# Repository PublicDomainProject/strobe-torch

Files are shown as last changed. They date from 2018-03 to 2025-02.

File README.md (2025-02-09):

# Strobe Torch
## Purpose
Little flashlight (or torch in UK) to calibrate the speed of a turntable with the help of a strobe disc or the strobe rings along the platter.

To use such strobe discs one needs a light source with a 50, 60 or 300 Hz strobe light. In the older days a simple light bulb with filament was enough to did the job. In the time of LEDs and compact fluorescent light sources one needs an additional helper like this to work with a strobe disc.

The needed frequency depends on your strobe disc. Most of them have at least 50 and 60 Hz in parallel (or two sides). There are "high-resolution" strobe discs that need a 300 Hz light source for calibration.

Also because this strobe torch uses a crystal oscillator it is more precise than a light bulb.

## Usage
The device is designed to be very simple to use.

There are three momentary buttons on the front. Each button represents one frequency. So simply press the 50 Hz button and you get a white light beam that flickers with 50 Hz.

When you release the button, the light goes off and the device consumes no energy.

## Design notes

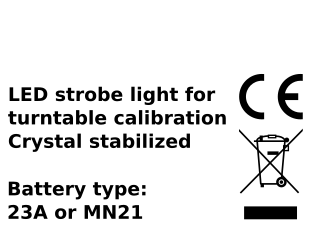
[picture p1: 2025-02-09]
case/Teko 11123 sticker white.png

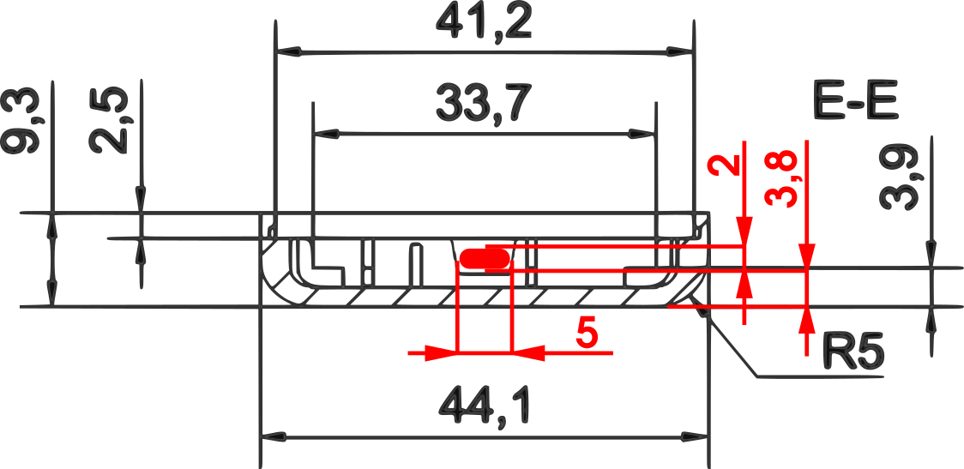
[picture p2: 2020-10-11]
case/Teko 11123 milling.png

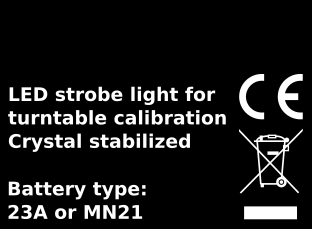
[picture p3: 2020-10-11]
case/Teko 11123 sticker.png

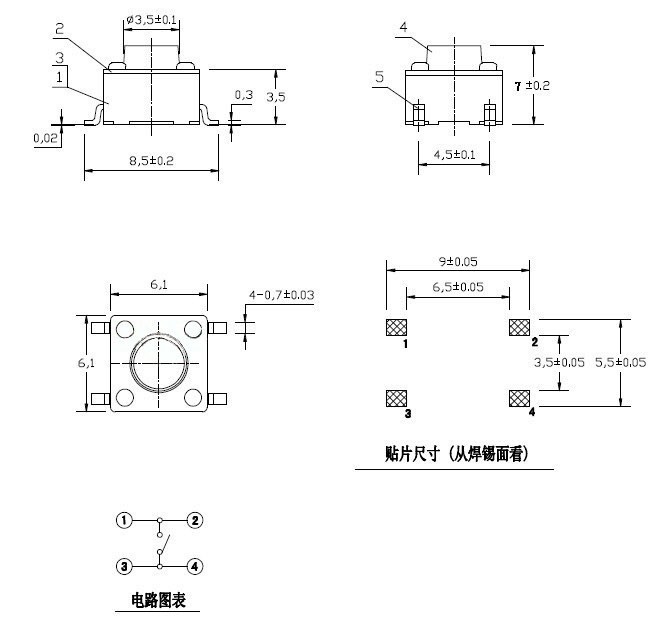
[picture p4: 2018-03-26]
datasheets/HTB1ZU.EGVXXXXXcXXXXq6xXFXXXH.jpg

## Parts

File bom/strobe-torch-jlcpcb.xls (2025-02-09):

Comment | Designator | Footprint | JLCPCB Part #
100n Unpolarized capacitor | C1 | 805
20pF Unpolarized capacitor | C2, C3 | 603
LED White Sideemitting 2.8*1,2*0,8mm | D1, D2 | 215
LED Green InGaN | D3 | 603 | C2288
BAT54A schottky barrier diode | D4, D5 | SOT-23 | C83936
BSS138 50V Vds, 0.22 A Id, N-channel MOSFET | Q1 | SOT-23 | C52895
1k8 Resistor | R1 | 603
150 Resistor | R2 | 603
Push button switch, SPST | SW1, SW3 | FSM6JSMA | C178262
ATTINY25V-10SU 2kB Flash, 128B EEPROM | U1 | SO-8 Wide 5.3x6.2mm
Crystal 4.9152MHz, two pin, SMD | Y1 | HC49-SD | C21921

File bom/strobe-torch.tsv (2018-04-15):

References | Qty | Description | Package | Manufacturer | Partnummer
BT1 | 1 | Battery compartment of the case |  | Teko | 1112x
C1 | 1 | 100n Unpolarized capacitor | 0805
C2, C3 | 2 | 20pF Unpolarized capacitor | 0603
D1, D2 | 2 | LED White Sideemitting 2.8*1,2*0,8mm | 215 | Xiasongxin | 215 White SMD LED 2.8*1,2*0,8mm
D3 | 1 | LED Green InGaN | 0603 | Everlight | 19-213/GHC-XS1T1N/3T
D4, D5 | 2 | BAT54A schottky barrier diode | SOT-23
Q1 | 1 | BSS138 50V Vds, 0.22 A Id, N-channel MOSFET | SOT-23
R1 | 1 | 1k8 Resistor | 0603
R2 | 1 | 150 Resistor | 0603
SW1, SW2, SW3 | 3 | Push button switch, SPST | PTS645
U1 | 1 | ATTINY25V-10SU 2kB Flash, 128B EEPROM | SO-8 Wide 5.3x6.2mm | Microchip
Y1 | 1 | Crystal 4.9152MHz, two pin, SMD | HC49-SD

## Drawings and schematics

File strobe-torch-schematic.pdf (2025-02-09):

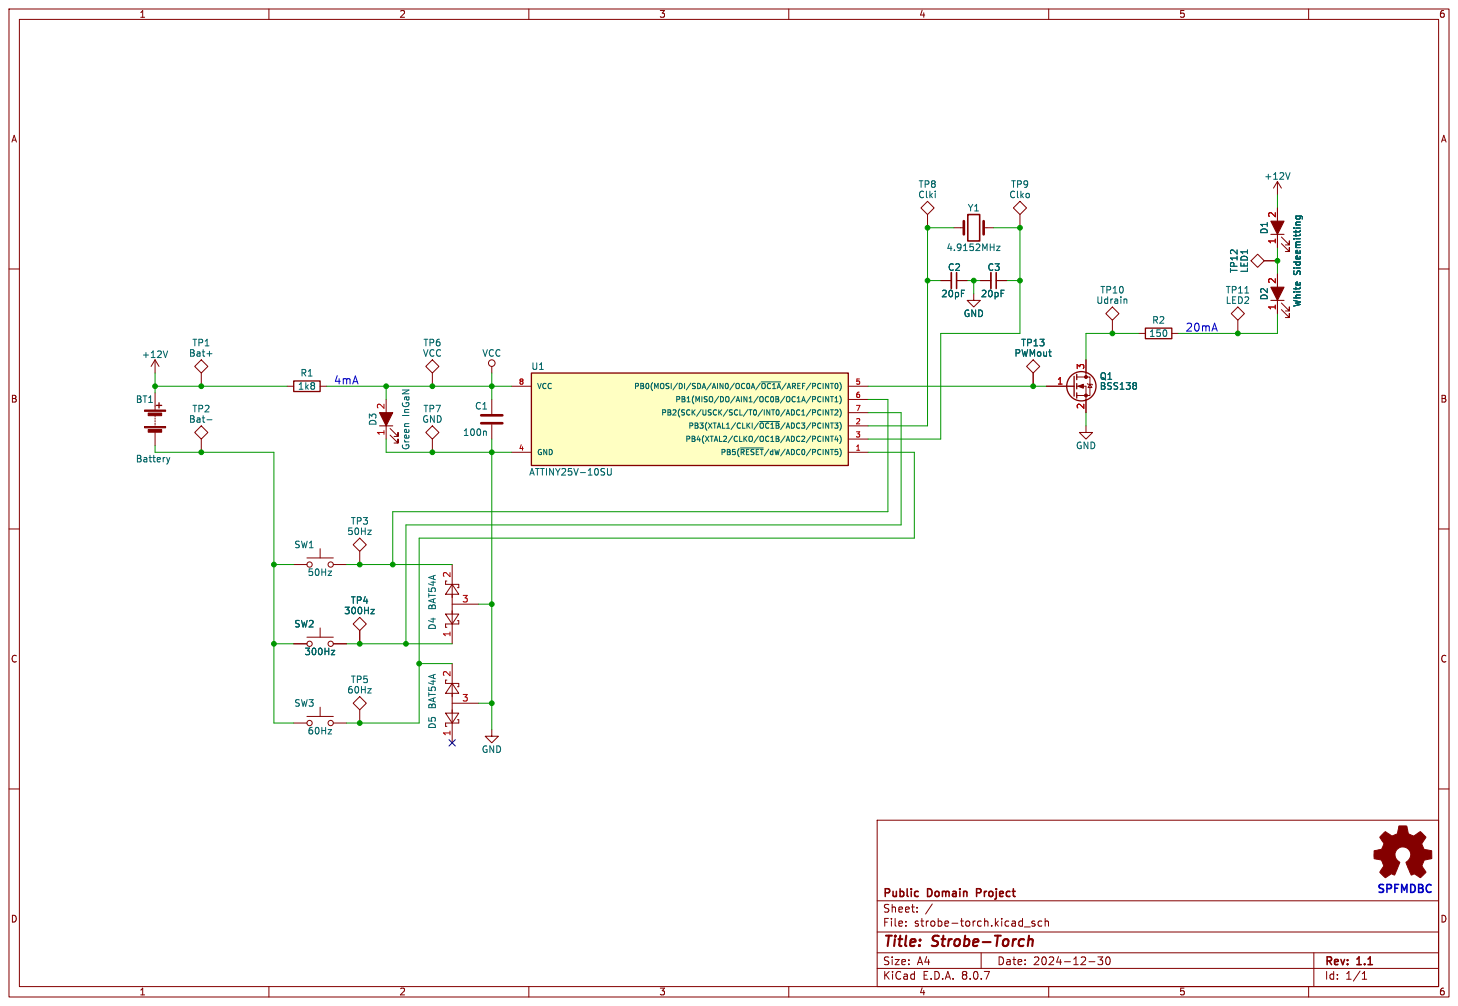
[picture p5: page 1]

1 2 D3 Green InGaN TP7 GND GND

Id: 1/1 Title: Strobe-Torch

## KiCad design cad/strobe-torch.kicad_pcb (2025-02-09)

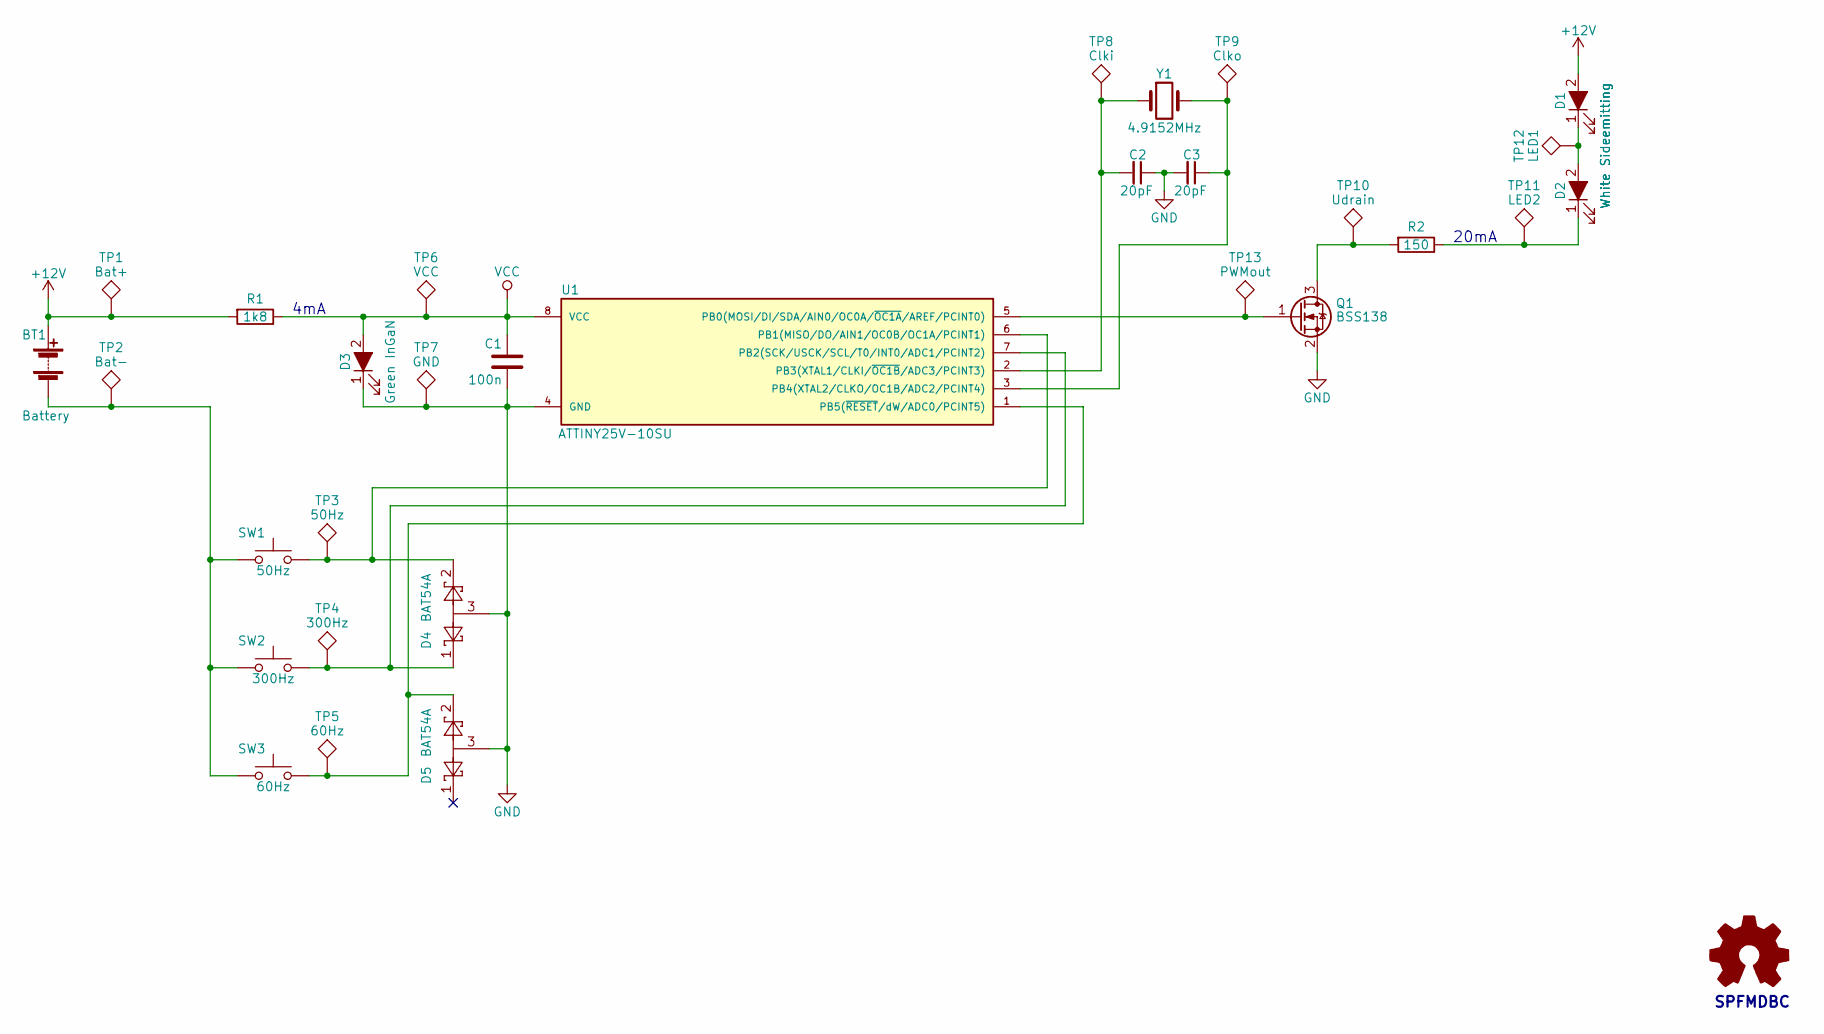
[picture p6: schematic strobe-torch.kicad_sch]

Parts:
BT1: Battery; Teko_1112x_battery_compartment
C1: 100n; C_0805
C2, C3: 20pF; C_0603
D1, D2: White Sideemitting; LED_215; Partnummer 215 White SMD LED 2.8*1,2*0,8mm
D3: Green InGaN; LED_0603; Partnummer 19-213/GHC-XS1T1N/3T
D4, D5: BAT54A; SOT-23
Q1: BSS138; SOT-23
R1: 1k8; R_0603
R2: 150; R_0603
SW1: 50Hz; SW_SPST_FSM6JSMA
SW2: 300Hz; SW_SPST_FSM6JSMA
SW3: 60Hz; SW_SPST_FSM6JSMA
TP1: Bat+; Measurement_Point_Round-SMD-Pad_Small
TP2: Bat-; Measurement_Point_Round-SMD-Pad_Small
TP3: 50Hz; Measurement_Point_Round-SMD-Pad_Small
TP4: 300Hz; Measurement_Point_Round-SMD-Pad_Small
TP5: 60Hz; Measurement_Point_Round-SMD-Pad_Small
TP6: VCC; Measurement_Point_Round-SMD-Pad_Small
TP7: GND; Measurement_Point_Round-SMD-Pad_Small
TP8: Clki; Measurement_Point_Round-SMD-Pad_Small
TP9: Clko; Measurement_Point_Round-SMD-Pad_Small
TP10: Udrain; Measurement_Point_Round-SMD-Pad_Small
TP11: LED2; Measurement_Point_Round-SMD-Pad_Small
TP12: LED1; Measurement_Point_Round-SMD-Pad_Small
TP13: PWMout; Measurement_Point_Round-SMD-Pad_Small
U1: ATTINY25V-10SU; SO-8_5.3x6.2mm_Pitch1.27mm
Y1: 4.9152MHz; Crystal_SMD_HC49-SD

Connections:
+12V: BT1.1 (+), D1.2 (A), R1.2, TP1.1
GND: C1.2, C2.1, C3.2, D3.1 (K), D4.3, D5.3, Q1.2 (S), TP7.1, U1.4 (GND)
unnamed: BT1.2 (-), SW1.1, SW2.1, SW3.1, TP2.1
unnamed: D1.1 (K), D2.2 (A), TP12.1
unnamed: D2.1 (K), R2.1, TP11.1
unnamed: Q1.3 (D), R2.2, TP10.1
unnamed: Q1.1 (G), TP13.1, U1.5 (PB0(MOSI/DI/SDA/AIN0/OC0A/~OC1A/AREF/PC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)
unnamed: D4.2, SW1.2, TP3.1, U1.6 (PB1(MISO/DO/AIN1/OC0B/OC1A/PCINT1))
unnamed: D4.1, SW2.2, TP4.1, U1.7 (PB2(SCK/USCK/SCL/T0/INT0/ADC1/PCINT2))
unnamed: C2.2, TP8.1, U1.2 (PB3(XTAL1/CLKI/~OC1B/ADC3/PCINT3)), Y1.1
unnamed: C3.1, TP9.1, U1.3 (PB4(XTAL2/CLKO/OC1B/ADC2/PCINT4)), Y1.2
unnamed: D5.2, SW3.2, TP5.1, U1.1 (PB5(~RESET/dW/ADC0/PCINT5))
VCC: C1.1, D3.2 (A), R1.1, TP6.1, U1.8 (VCC)

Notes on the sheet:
4mA
20mA
SPFMDBC

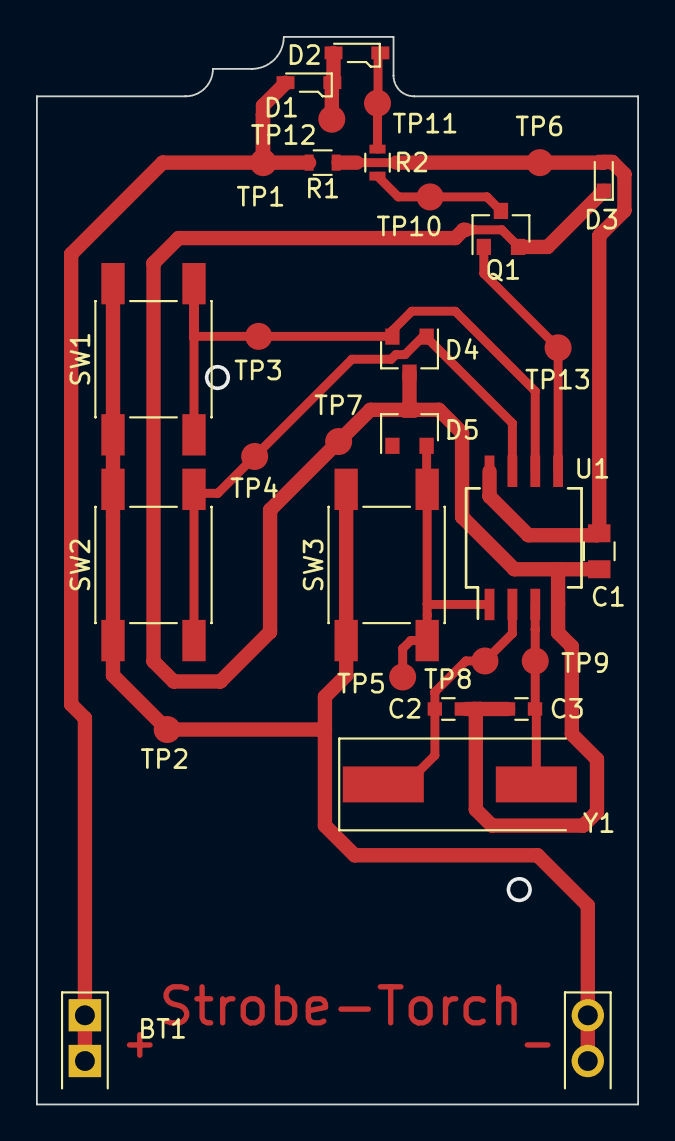
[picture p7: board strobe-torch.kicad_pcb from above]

Board: 2 copper layers, 33.4 x 59.3 mm, 30 parts (0 on the bottom side), 13 nets.

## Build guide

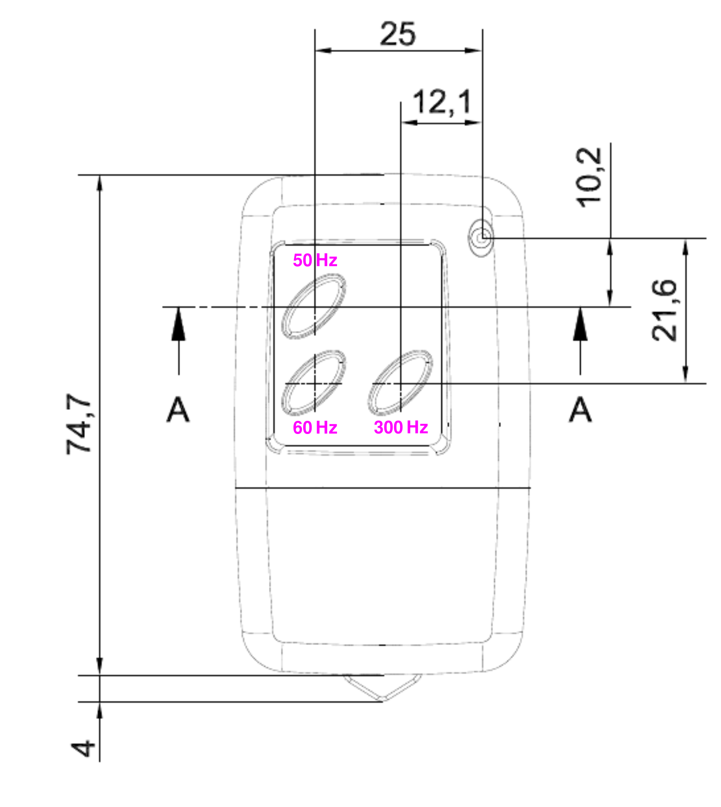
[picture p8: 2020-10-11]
case/Teko 11123 printing.png

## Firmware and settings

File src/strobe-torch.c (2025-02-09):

/***************************************************************************
 * Strobe-Torch
 * (c) 2018 Christoph Zimmermann
 *
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
 * Written by Christoph Zimmermann <nuess0r@pdproject.org>, 2018.
 *
 ***************************************************************************
 * Fuse bit configuration:
 *   - Production setting with 60 Hz mode and disabled reset input
 *   Ext. Crystal Osc.; Frequency 3.0-8.0 MHz; Start-up time PWRDWN/RESET: 258 CK/14 CK + 4.1 ms; [CKSEL=1100 SUT=00]
 *   Clock output on PORTB4 disabled; [CKOUT=0]
 *   Divide clock by 8 internally enabled; [CKDIV8=0]
 *   Brown-out detection disabled; [BODLEVEL=111]
 *   Debug Wire disabled; [DWEN=1] * (only during development)
 *   Preserve EEPROM memory through the Chip Erase cycle disabled; [EESAVE=0]
 *   Reset Disabled (Enable PB5 as i/o pin); [RSTDISBL=0] *
 *   Serial program downloading (SPI) enabled; [SPIEN=0] *
 *   Watch-dog Timer disabled; [WDTON=0]
 *   Self Programming disabled; [SELFPRGEN=0]
 *   AVRDUDE_FUSEBITS = -U hfuse:w:0x5F:m -U lfuse:w:0x4C:m -U efuse:w:0xFF:m

 *   - Development setting without 60 Hz mode (two button only) and enabled reset input (reprogramming possible)
 *   Ext. Crystal Osc.; Frequency 3.0-8.0 MHz; Start-up time PWRDWN/RESET: 258 CK/14 CK + 4.1 ms; [CKSEL=1100 SUT=00]
 *   Clock output on PORTB4 disabled; [CKOUT=0]
 *   Divide clock by 8 internally enabled; [CKDIV8=0]
 *   Brown-out detection disabled; [BODLEVEL=111]
 *   Debug Wire disabled; [DWEN=1] * (only during development)
 *   Preserve EEPROM memory through the Chip Erase cycle disabled; [EESAVE=0]
 *   Reset Disabled (Enable PB5 as i/o pin); [RSTDISBL=0] *
 *   Serial program downloading (SPI) enabled; [SPIEN=0] *
 *   Watch-dog Timer disabled; [WDTON=0]
 *   Self Programming disabled; [SELFPRGEN=0]
 *   AVRDUDE_FUSEBITS = -U hfuse:w:0xDF:m -U lfuse:w:0x4C:m -U efuse:w:0xFF:m
 *
 * Lock bit configuration:
 *   Mode 3: Further programming and verification disabled
 *   AVRDUDE_LOCKBITS = -V -U lock:w:0xFC:m
 *
 ***************************************************************************/

#include <stdlib.h>
#include <stdint.h>

#include <avr/io.h>
#include <avr/sleep.h>
#include <avr/power.h>

typedef enum {MODE_50HZ, MODE_60HZ, MODE_300HZ, MODE_FALSE} mode_t;

/************ Device specific definitions ****/

/* Pinning of the buttons to the input pins (all on Port B) */
#define BTN_50HZ  1
#define BTN_60HZ  5
#define BTN_300HZ 2

/* The LED is connected to Port B, Pin 1 (OC1A) */
#define PWM_OUT   0

/* The frequency of the PWM will be Timer Clock 1 Frequency divided by (OCR1C value + 1). See the
 * equation in the data sheet, page 87.
 *
 * The actual LED frequency is 4.9152 MHz/256/8/(x+1), x =
 *   23 = 100 Hz
 *   19 = 120 Hz
 *    3 = 600 Hz */
typedef enum {PWM_50HZ = 23, PWM_60HZ = 19, PWM_300HZ = 3} compare_value_t;


/************ Device specific functions ****/

static inline void init() {
     /* Power Reduction Register
      *   Bit 3 – PRTIM1: Power Reduction Timer/Counter1 disabled
      *   Bit 2 – PRTIM0: Power Reduction Timer/Counter0 enabled
      *   Bit 1 – PRUSI: Power Reduction USI enabled
      *   Bit 0 – PRADC: Power Reduction ADC enabled */
    PRR = 0x07;

    /* Set clock prescaler to 256
     *   This sets the Frequency to 4.9152 MHz/256 = 19.2 kHz */
    clock_prescale_set(0x08);

    /* Activate internal pull-up resistors */
    PORTB |= (1 << BTN_50HZ) | (1 << BTN_60HZ) | (1 << BTN_300HZ);

    /* Set PWM pin as output */
    DDRB = (1 << PWM_OUT);
}

/* Reads the buttons and returns the according operating mode.
 *   If more than one button is pressed return value is MODE_FALSE */
static inline mode_t read_buttons() {
    mode_t mode;
    uint8_t btn_pressed = 0;

    /* Buttons are low-active */
    /* Read first the button connected to the (later) disabled reset input
     * If the reset input is still active this pin will always read 0 --> read this and then
     * it gets overwritten by other buttons */
    if((PINB  & (1 << BTN_60HZ)) == 0) {
        mode = MODE_60HZ;
        btn_pressed++;
    }
    if((PINB  & (1 << BTN_50HZ)) == 0) {
        mode = MODE_50HZ;
        btn_pressed++;
    }
    if((PINB  & (1 << BTN_300HZ)) == 0) {
        mode = MODE_300HZ;
        btn_pressed++;
    }

    if(btn_pressed >= 1) {
        return mode;
    }
    else {
        return MODE_FALSE;
    }
}

static inline void set_pwm(compare_value_t compare_value) {
    /* Initialize the timer/counter 1
     *   Clear Timer/Counter on Compare Match (CTC1 = 1)
     *   Pulse Width Modulator A enabled (PWM1A = 1)
     *   Comparator A mode set to toggle both the normal and inverted OC1A output line (COM1A1, COM1A0 = 01)
     *   Set Timer 1 prescaler to 8 (CS13...CS10 = 0100)
     */
    TCCR1 = (1<<CTC1) | (1<<PWM1A) | (1<<COM1A0) | (1<<CS12);

    /* Set maximum for Timer/Counter1 */
    OCR1C = compare_value;
    OCR1A = (compare_value >> 1);
}


/*********************** Main app **********/
int main(void) {
    mode_t button_pressed;

    init();

    do {
        button_pressed = read_buttons();
    }
    while(button_pressed == MODE_FALSE);

    switch(button_pressed) {
    case (MODE_50HZ):
        set_pwm(PWM_50HZ);
    break;
    case (MODE_60HZ):
        set_pwm(PWM_60HZ);
    break;
    case (MODE_300HZ):
        set_pwm(PWM_300HZ);
    break;
    default:
    break;
    }

    /* Do nothing and go to sleep mode to save battery power */
    sleep_enable();
    sleep_cpu();
}

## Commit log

2018-03-01 initial commit of the prototype design with finished schematic as intended.
    [1-click-bom.tsv, strobe-torch.kicad_pcb, strobe-torch.sch]
2018-03-04 initial version of firmware.
    compiles, not tested on device yet.
    [strobe-torch.tsv]
2018-03-04 More power reduction
2018-03-13 version with ISR to toggle pwm pin direction and pull-up resistor to drive an external transistor
2018-03-13 fixed missing code to enable timer interrupt mask
    [strobe-torch.c]
2018-03-18 Prototype hardware changed to ATtiny25
2018-03-26 changed pinning according to pcb layout. changed from OC1A to !OC1A (inverted) output.
    [strobe-torch.c]
2018-03-26 Updated schematic (Output MOSFET and change to Shottky diodes, changed pinning to optimize layout)
    Created footprints for Teko case and side emitting LEDs
    Initial pcb layout
    [strobe-torch.kicad_pcb, strobe-torch.sch]
2018-03-26 Sticker for the backside of the case (unbranded with space for logo) and drawing to get the LED opening milled.
2018-04-15 finalized bill of material (BOM)
    [strobe-torch.tsv]
2018-04-15 fixed button pressed routine. works on final circuit with three buttons and disabled reset pin.
    [strobe-torch.c]
2018-04-18 added compiled binary ready to flash onto device.
2018-04-18 Applied needed modifications after production of first samples.
    [strobe-torch.kicad_pcb, strobe-torch.sch]
2018-04-18 Adding schematic as pdf and the exported pcb files for production (Gerber, pick and place data).
    [strobe-torch-Edge.Cuts.gbr, strobe-torch-F.Cu.gbr, strobe-torch-F.Paste.gbr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]
2018-04-26 Created a panel with ten strobe-torch PCBs and a boarder that is wide enough to grab it in a SMD pick'n place machine. It is using v-cuts (break lines) to hold the PCBs together during production.
    [strobe-torch_panelized.kicad_pcb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]
2020-10-11 Add manufacturing drawings for TEKO 11123 case
2025-02-09 Change footprint of button and upgrade to KiCad 8
    [strobe-torch-Edge.Cuts.gbr, strobe-torch-Edge_Cuts.gbr, strobe-torch-F.Cu.gbr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]
2025-02-09 Add production files for the case sticker
    [strobe-torch-top.csv]
2025-02-09 Change button mapping. The two button case variant provides now 50 and 60 Hz instead of 50 and 300 Hz. Changed because the two button variant is easier to buy than the three button case.
    Make it work with avr-gcc 14

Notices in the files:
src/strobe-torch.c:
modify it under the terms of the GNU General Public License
